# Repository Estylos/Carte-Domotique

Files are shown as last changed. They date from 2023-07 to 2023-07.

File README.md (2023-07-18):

# Carte de contrôle domotique avec ESP32

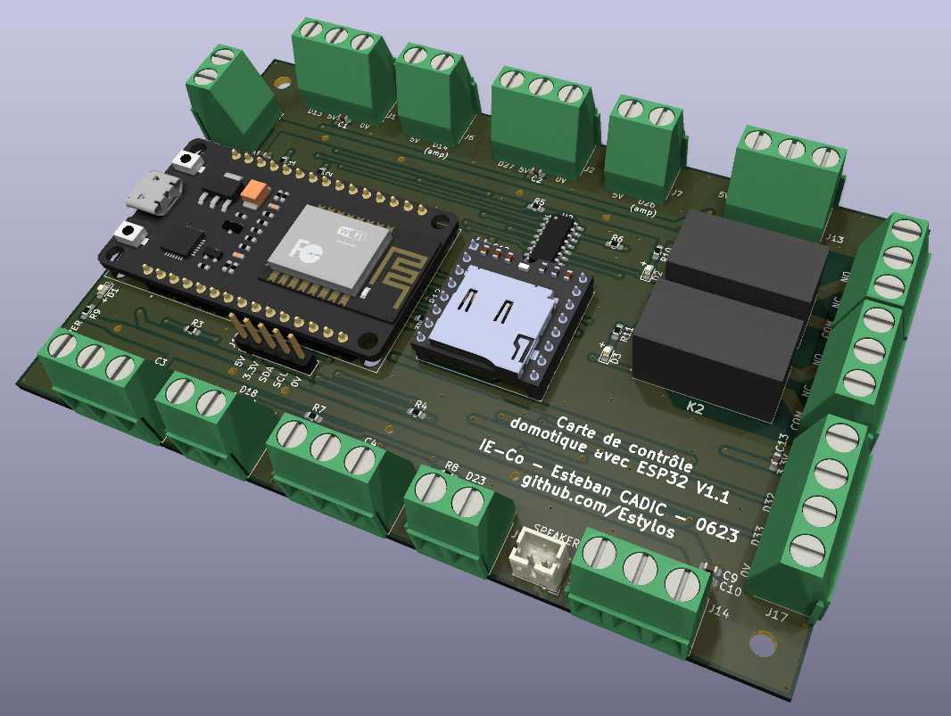
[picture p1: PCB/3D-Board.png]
Visuel 3D


Ce projet prend place dans le cadre de mon stage de fin de 1ère année de cycle ingénieur à l'école Grenoble INP - Esisar, effectué dans le bureau d'études en conception électronique [IE-Concept](https://www.ie-concept.fr/). Un grand merci à l'entreprise de m'avoir permis d'effectuer ce stage dans d'excellentes conditions ainsi que d'autoriser la publication du travail que j'ai pu mener.

## Présentation

L'objectif de ce stage consistait à l'installation d'un système domotique permettant de contrôler les climatiseurs de la société, ainsi que monitorer différents capteurs (température, humidité, présence…) le tout depuis Home Assistant. Ce repo contient seulement la carte électronique basée sur un ESP32 DevKit V1, réalisé sur KiCad ainsi que son boîtier modélisé sur Fusion 360.  

## Objectifs de la carte

La carte domotique conçue permet le branchement de 4 rubans ou anneaux de LEDs adressables WS2812 (pour l'indication lumineuse allant avec le contrôle des clims), 4 LEDs infrarouges, 2 sorties PWM, 1 sortie I2C, 2 relais, 1 port divers avec deux sources de tension (5 et 3.3V) et 2 GPIOs (utilisables par l’ADC1 de l’ESP32). La carte permet aussi le branchement d'un DFPlayer Mini et d'un haut-parleur servant à la lecture de sons depuis une carte SD (et pilotable par Home Assistant).

L'ESP32 peut être configuré directement avec ESPHome, permettant une intégration directe avec Home Assistant. 

## Circuit

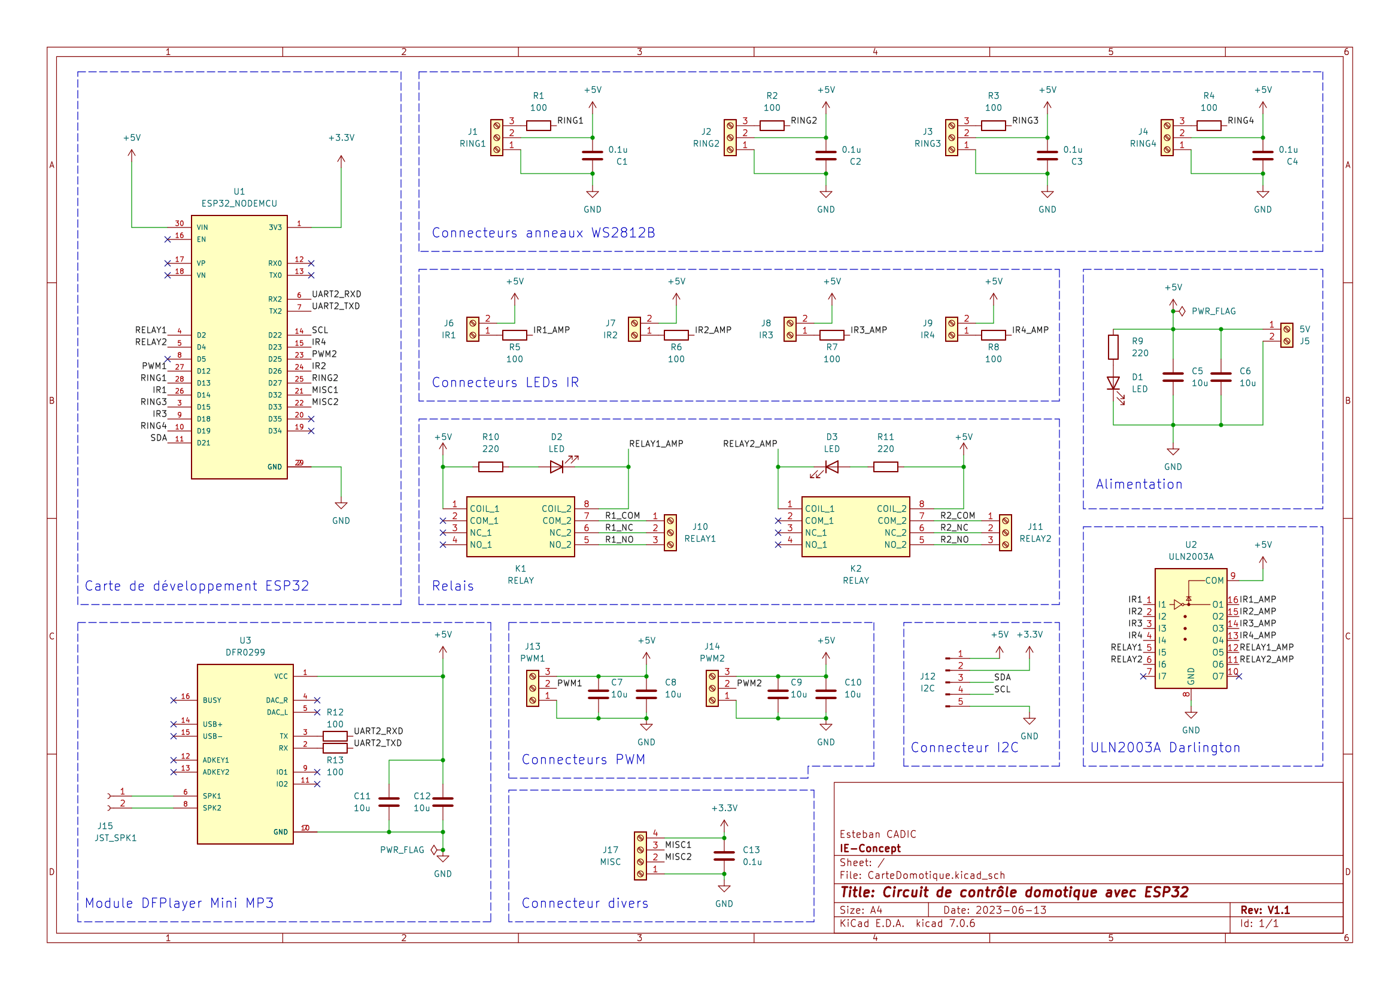
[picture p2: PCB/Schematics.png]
Circuit


Le circuit n'est pas d'une grande complexité. Il s'agit globalement d'un ESP32 avec des borniers à vis, 2 relais, un DFPlayer et quelques composants passifs : condensateurs pour le découplage et résistances pour la limitation de courant. Un réseau de transistors Darlington (ULN2003A) est utilisé afin d'amplifier et de monter à 5V les sorties des LEDs infrarouges contrôlant les climatiseurs et les sorties pour les 2 relais.

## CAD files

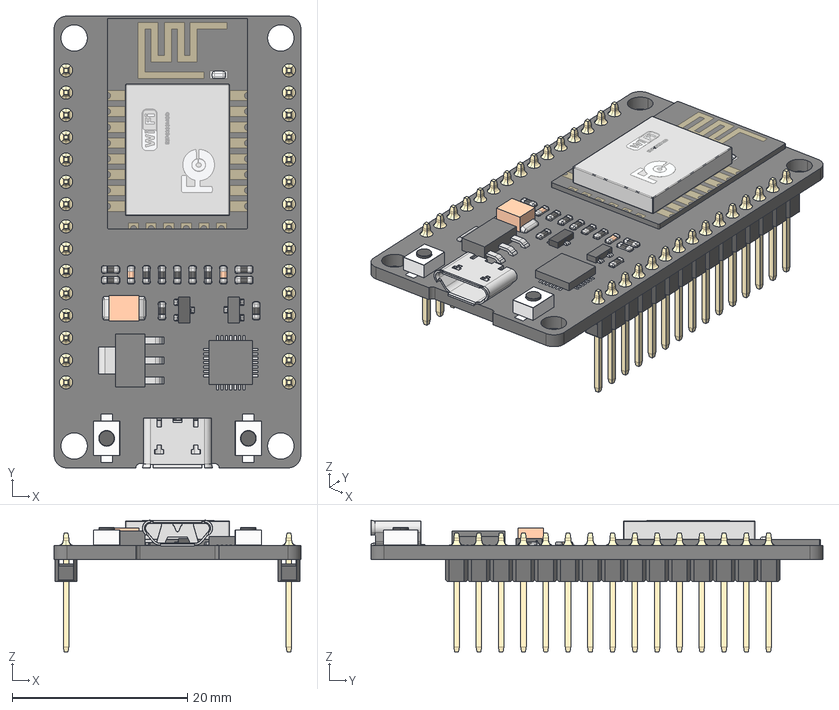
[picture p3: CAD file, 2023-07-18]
PCB/KiCad Files/MISC/ESP32-DEVKIT-V1/esp32_dev_kit_v1_asm.stp
28.1 x 51.5 x 15.0 mm
PCB
PIN x 30
WIFI_CARD_2
RECTANGULARCHIP_2
MICROCHIP_2
TANCHIP_2
TRANSISTOR_3-LEG_2
RESISTOR1_2 x 11
RESISTOR2-32_2 x 2
TRANSISTOR_3-LEG2_2
BUTTONFLASH-13_2 x 2
BUTTONFLASH-14_2 x 2
USB_SOCKET_2

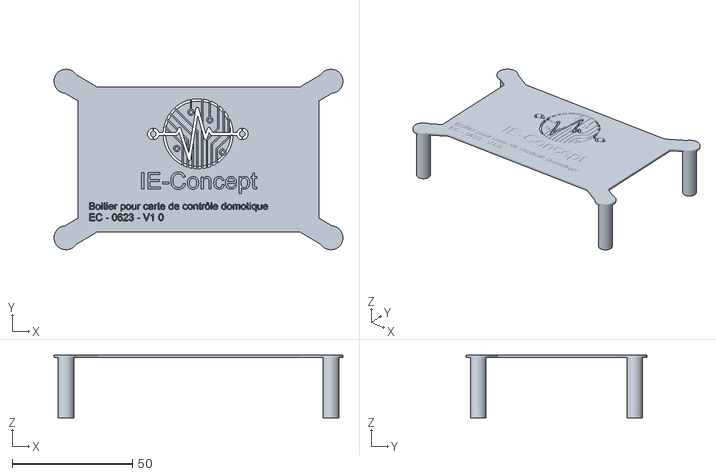
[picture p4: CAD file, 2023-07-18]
CASE/Boite domo TOP v1.stl
120.0 x 75.0 x 26.0

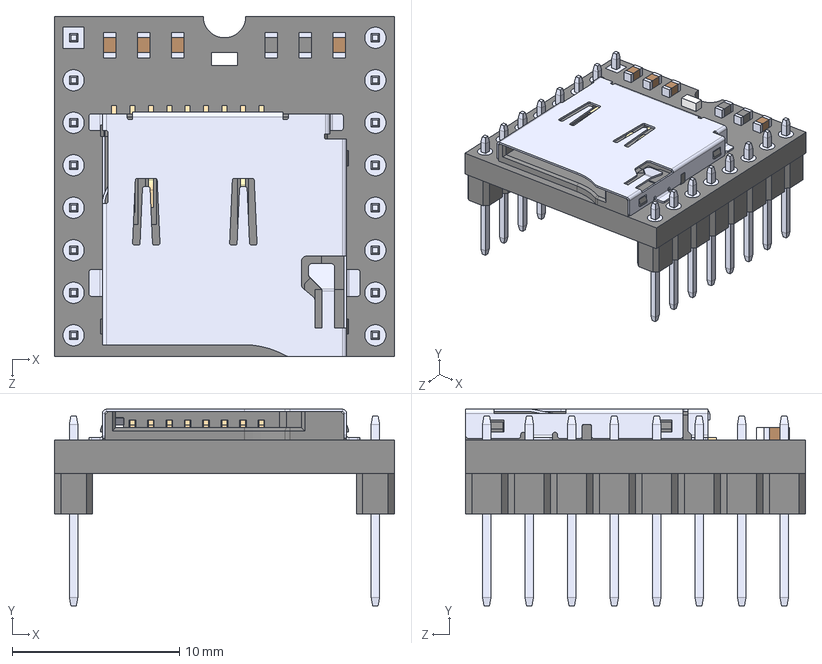
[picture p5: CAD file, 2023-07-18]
PCB/KiCad Files/MISC/DFPLAYER/DFR0299.step
20.3 x 11.8 x 20.3 mm

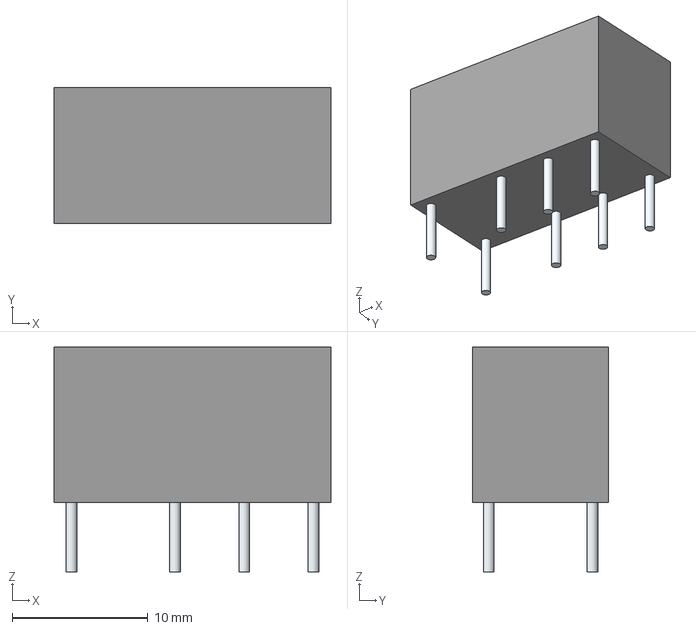
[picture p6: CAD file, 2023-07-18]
PCB/KiCad Files/MISC/RELAY/J104D2C24VDC.20S.stp
20.4 x 9.97 x 16.5 mm
Leads

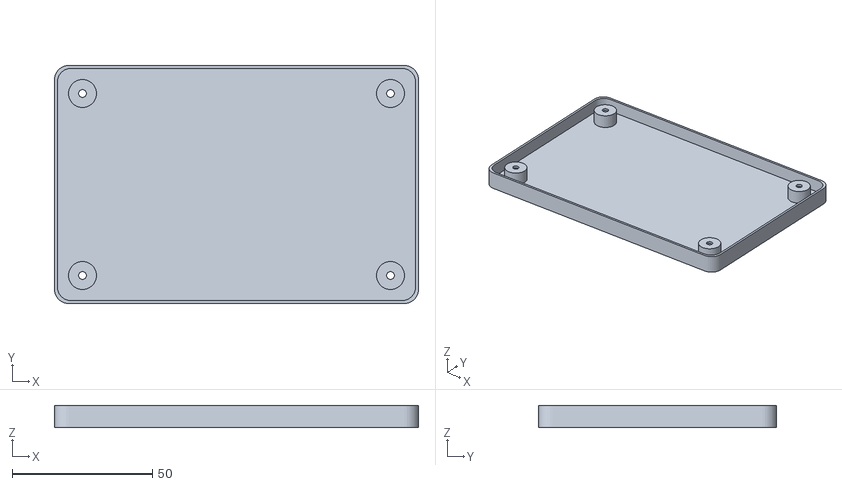
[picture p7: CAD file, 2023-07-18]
CASE/Boite domo BOT v1.stl
130.0 x 85.0 x 8.00

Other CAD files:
CASE/Boite domo v1.f3d

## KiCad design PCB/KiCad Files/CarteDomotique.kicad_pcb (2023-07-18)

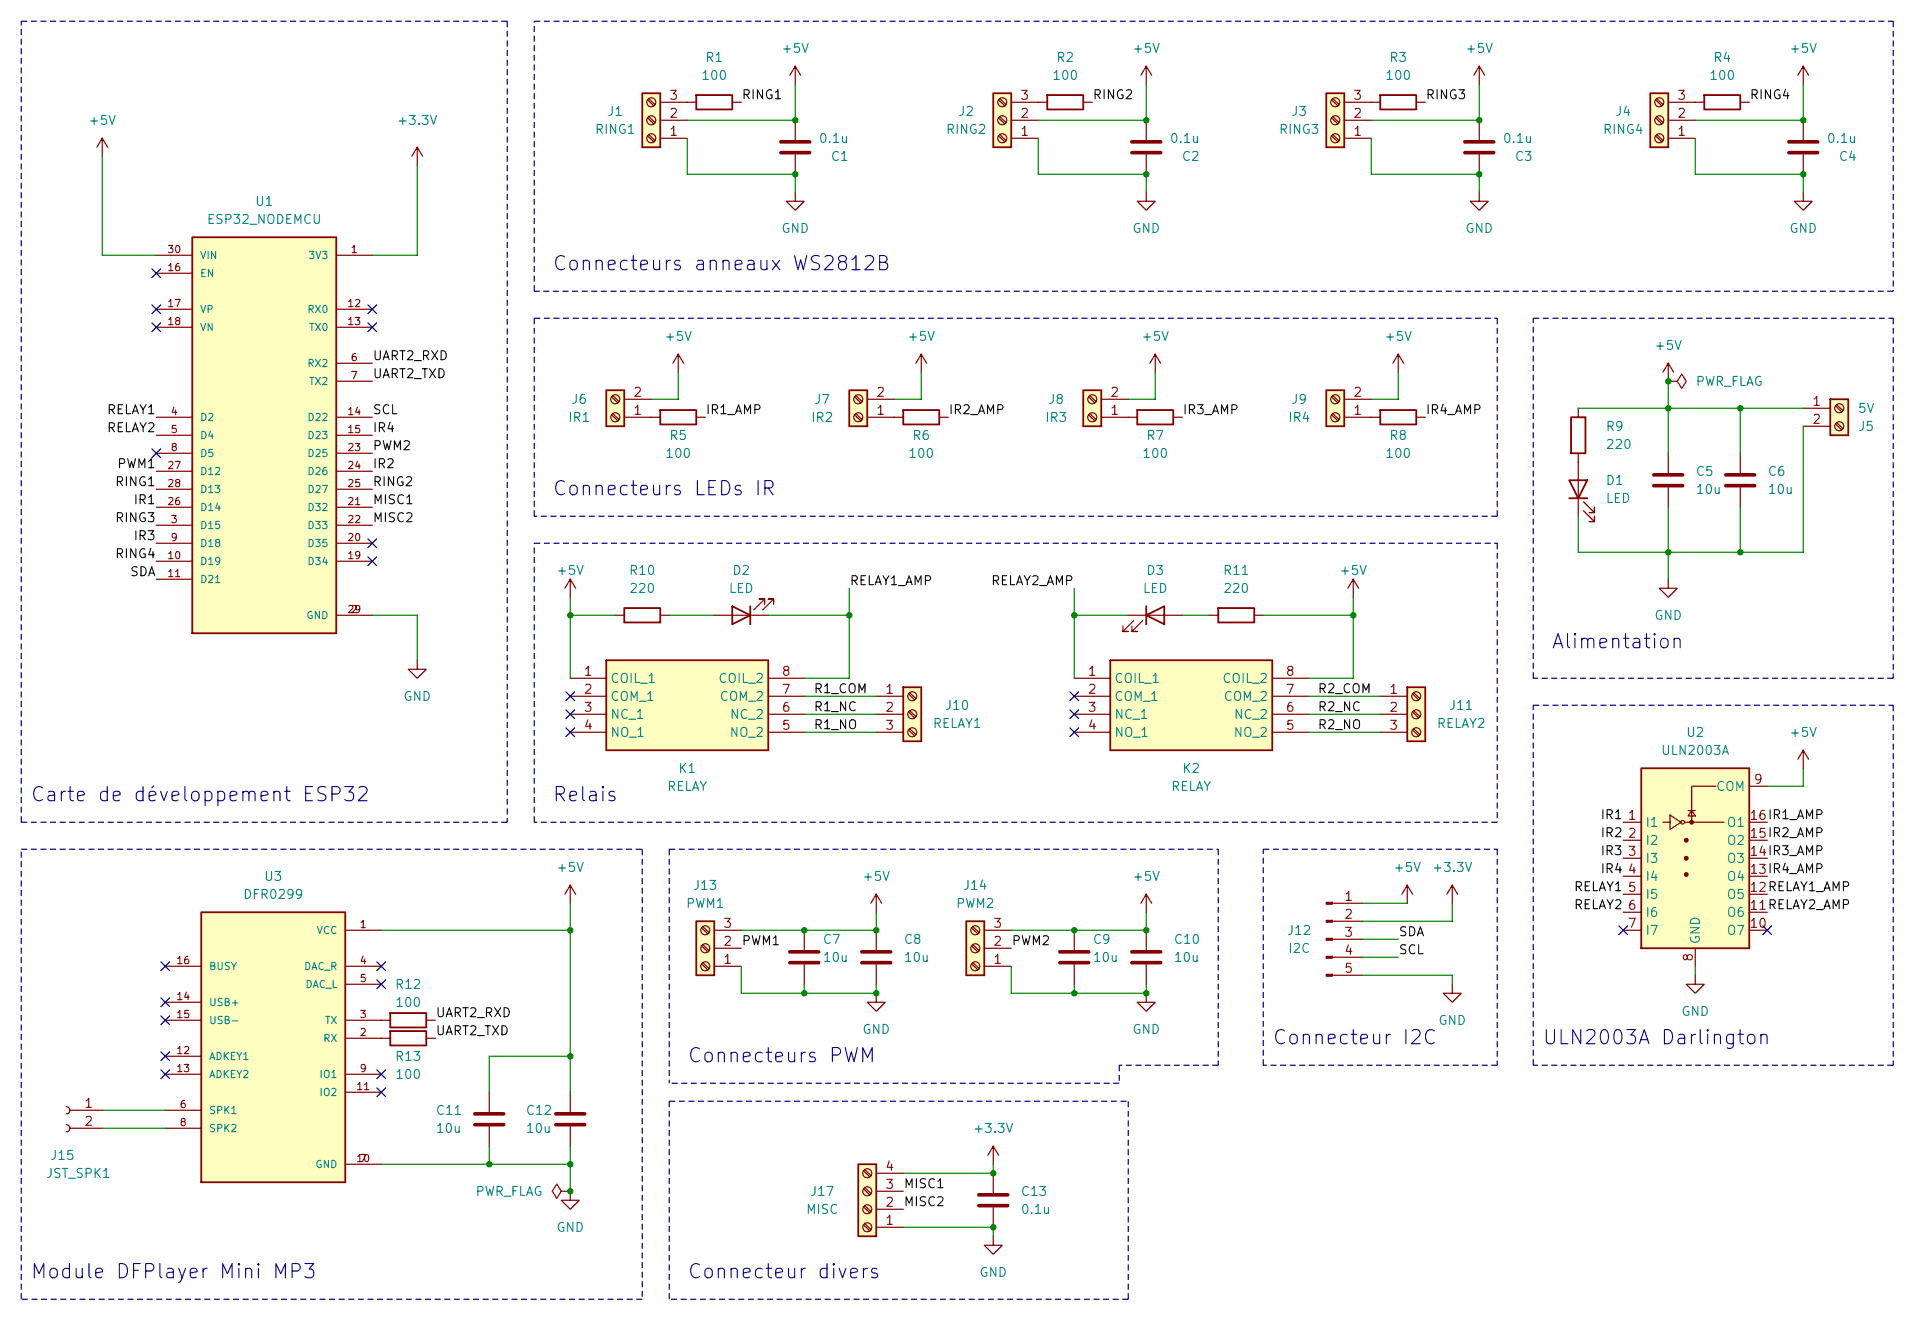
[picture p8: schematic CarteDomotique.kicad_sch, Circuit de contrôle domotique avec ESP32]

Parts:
C1, C2, C3, C4, C13: 0.1u; C_0603_1608Metric_Pad1.08x0.95mm_HandSolder; LCSC Part C14665
C5, C6, C7, C8, C9, C10, C11, C12: 10u; C_0603_1608Metric_Pad1.08x0.95mm_HandSolder; Farnell 9452176
D1, D2, D3: LED; LED_0603_1608Metric_Pad1.05x0.95mm_HandSolder; LCSC Part C84263
J1: RING1; TerminalBlock_bornier-3_P5.08mm; LCSC Part C72334
J2: RING2; TerminalBlock_bornier-3_P5.08mm; LCSC Part C72334
J3: RING3; TerminalBlock_bornier-3_P5.08mm; LCSC Part C72334
J4: RING4; TerminalBlock_bornier-3_P5.08mm; LCSC Part C72334
J5: 5V; TerminalBlock_bornier-2_P5.08mm; LCSC Part C8465
J6: IR1; TerminalBlock_bornier-2_P5.08mm; LCSC Part C8465
J7: IR2; TerminalBlock_bornier-2_P5.08mm; LCSC Part C8465
J8: IR3; TerminalBlock_bornier-2_P5.08mm; LCSC Part C8465
J9: IR4; TerminalBlock_bornier-2_P5.08mm; LCSC Part C8465
J10: RELAY1; TerminalBlock_bornier-3_P5.08mm; LCSC Part C72334
J11: RELAY2; TerminalBlock_bornier-3_P5.08mm; LCSC Part C72334
J12: I2C; PinHeader_1x05_P2.54mm_Vertical; LCSC Part C492404
J13: PWM1; TerminalBlock_bornier-3_P5.08mm; LCSC Part C72334
J14: PWM2; TerminalBlock_bornier-3_P5.08mm; LCSC Part C72334
J15: JST_SPK1; JST_PH_B2B-PH-K_1x02_P2.00mm_Vertical; Farnell 9492534
J17: MISC; TerminalBlock_bornier-4_P5.08mm; LCSC Part C2915641
K1, K2: RELAY; J104D2C24VDC20S; Manufacturer_Part_Number J104D2C24VDC.20S; Digi-Key 2449-J104D2C5VDC.20S-ND
R1, R2, R3, R4, R12, R13: 100; R_0603_1608Metric_Pad0.98x0.95mm_HandSolder; LCSC Part C22775
R5, R6, R7, R8: 100; R_0603_1608Metric_Pad0.98x0.95mm_HandSolder; LCSC Part C107696
R9, R10, R11: 220; R_0603_1608Metric_Pad0.98x0.95mm_HandSolder; LCSC Part C107696
U1: ESP32_NODEMCU; MODULE_ESP32_DEVKIT_V1; PARTREV N/A; JLCPCB BOM 0
U2: ULN2003A; SOIC-16_3.9x9.9mm_P1.27mm; Farnell 2628016
U3: DFR0299; MODULE_DFR0299; JLCPCB BOM 0

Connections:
+3.3V: C13.1, J12.2, J17.4, U1.1 (3V3)
+5V: C1.1, C2.1, C3.1, C4.1, C5.1, C6.1, C7.1, C8.1, C9.1, C10.1, C11.1, C12.1, J1.2, J2.2, J3.2, J4.2, J5.1, J6.2, J7.2, J8.2, J9.2, J12.1, J13.3, J14.3, K1.1 (COIL_1), K2.8 (COIL_2), R9.1, R10.1, R11.1, U1.30 (VIN), U2.9 (COM), U3.1 (VCC)
/IR1: U1.26 (D14), U2.1 (I1)
/IR1_AMP: R5.1, U2.16 (O1)
/IR2: U1.24 (D26), U2.2 (I2)
/IR2_AMP: R6.1, U2.15 (O2)
/IR3: U1.9 (D18), U2.3 (I3)
/IR3_AMP: R7.1, U2.14 (O3)
/IR4: U1.15 (D23), U2.4 (I4)
/IR4_AMP: R8.1, U2.13 (O4)
/MISC1: J17.3, U1.21 (D32)
/MISC2: J17.2, U1.22 (D33)
/PWM1: J13.2, U1.27 (D12)
/PWM2: J14.2, U1.23 (D25)
/R1_COM: J10.1, K1.7 (COM_2)
/R1_NC: J10.2, K1.6 (NC_2)
/R1_NO: J10.3, K1.5 (NO_2)
/R2_COM: J11.1, K2.7 (COM_2)
/R2_NC: J11.2, K2.6 (NC_2)
/R2_NO: J11.3, K2.5 (NO_2)
/RELAY1: U1.4 (D2), U2.5 (I5)
/RELAY1_AMP: D2.1 (K), K1.8 (COIL_2), U2.12 (O5)
/RELAY2: U1.5 (D4), U2.6 (I6)
/RELAY2_AMP: D3.1 (K), K2.1 (COIL_1), U2.11 (O6)
/RING1: R1.1, U1.28 (D13)
/RING2: R2.1, U1.25 (D27)
/RING3: R3.1, U1.3 (D15)
/RING4: R4.1, U1.10 (D19)
/SCL: J12.4, U1.14 (D22)
/SDA: J12.3, U1.11 (D21)
/UART2_RXD: R12.1, U1.6 (RX2)
/UART2_TXD: R13.1, U1.7 (TX2)
GND: C1.2, C2.2, C3.2, C4.2, C5.2, C6.2, C7.2, C8.2, C9.2, C10.2, C11.2, C12.2, C13.2, D1.1 (K), J1.1, J2.1, J3.1, J4.1, J5.2, J12.5, J13.1, J14.1, J17.1, U1.2 (GND), U1.29 (GND), U2.8 (GND), U3.7 (GND), U3.10 (GND)
unnamed: D1.2 (A), R9.2
unnamed: D2.2 (A), R10.2
unnamed: D3.2 (A), R11.2
unnamed: J1.3, R1.2
unnamed: J2.3, R2.2
unnamed: J3.3, R3.2
unnamed: J4.3, R4.2
unnamed: J6.1, R5.2
unnamed: J7.1, R6.2
unnamed: J8.1, R7.2
unnamed: J9.1, R8.2
unnamed: J15.1, U3.6 (SPK1)
unnamed: J15.2, U3.8 (SPK2)
unnamed: R13.2, U3.2 (RX)
unnamed: R12.2, U3.3 (TX)

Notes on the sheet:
Alimentation
Carte de développement ESP32
ULN2003A Darlington
Connecteurs PWM
Module DFPlayer Mini MP3
Connecteurs LEDs IR
Connecteur I2C
Relais
Connecteurs anneaux WS2812B
Connecteur divers

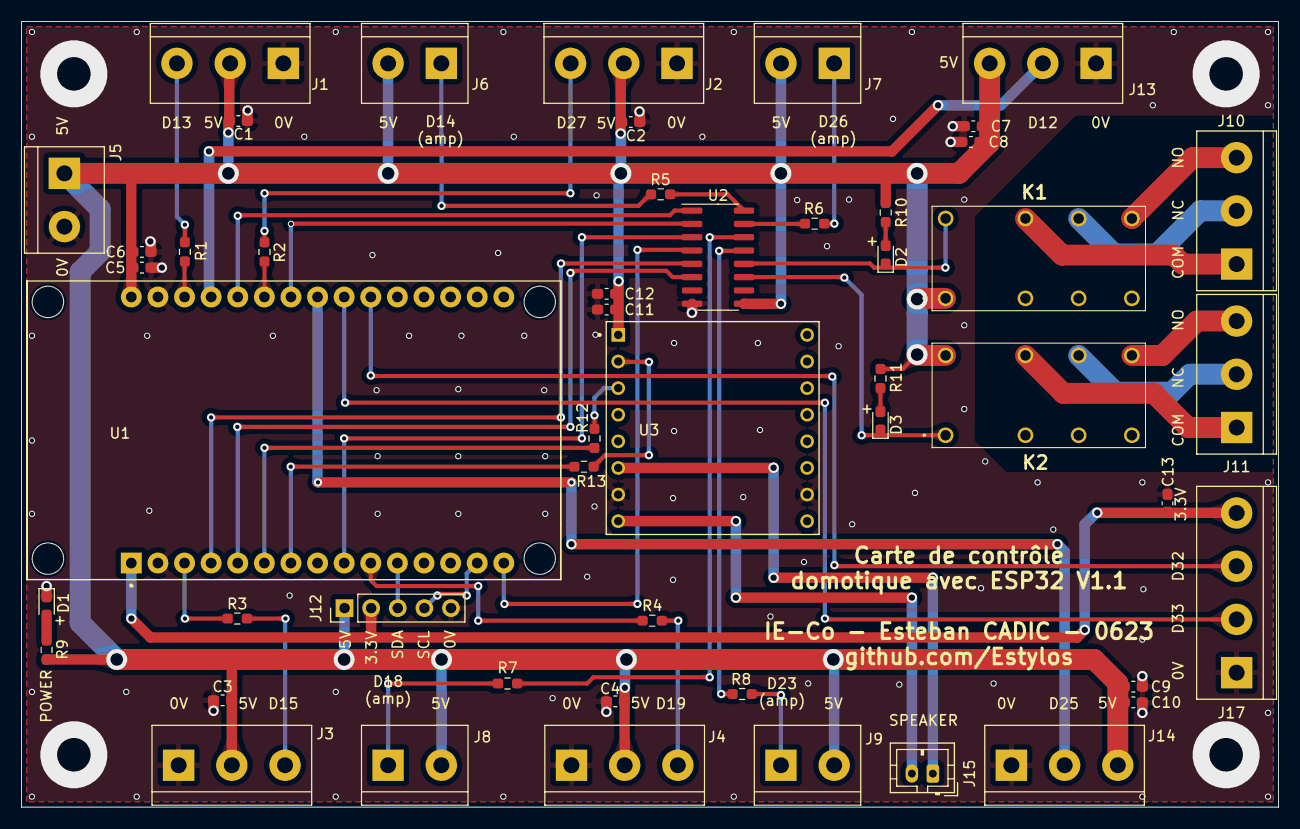
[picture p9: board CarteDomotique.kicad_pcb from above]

Board: 2 copper layers, 120.0 x 75.0 mm, 50 parts (0 on the bottom side), 48 nets.

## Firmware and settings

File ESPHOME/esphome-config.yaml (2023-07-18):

esphome:
  name: esp32-domo1
  friendly_name: ESP32 Domotique 1

# Carte : ESP32 NodeMCU (devkitv1)
esp32:
  board: nodemcu-32s
  framework:
    type: arduino

# Enable logging
logger:

# Enable Home Assistant API
api:
  encryption:
    key: ""

  # For DFPlayer
  services:
  - service: dfplayer_next
    then:
      - dfplayer.play_next:
  - service: dfplayer_previous
    then:
      - dfplayer.play_previous:
  - service: dfplayer_play
    variables:
      file: int
    then:
      - dfplayer.play: !lambda 'return file;'
  - service: dfplayer_play_loop
    variables:
      file: int
      loop_: bool
    then:
      - dfplayer.play:
          file: !lambda 'return file;'
          loop: !lambda 'return loop_;'
  - service: dfplayer_play_folder
    variables:
      folder: int
      file: int
    then:
      - dfplayer.play_folder:
          folder: !lambda 'return folder;'
          file: !lambda 'return file;'

  - service: dfplayer_play_loop_folder
    variables:
      folder: int
    then:
      - dfplayer.play_folder:
          folder: !lambda 'return folder;'
          loop: true

  - service: dfplayer_set_device_tf
    then:
      - dfplayer.set_device: TF_CARD

  - service: dfplayer_set_device_usb
    then:
      - dfplayer.set_device: USB

  - service: dfplayer_set_volume
    variables:
      volume: int
    then:
      - dfplayer.set_volume: !lambda 'return volume;'
  - service: dfplayer_set_eq
    variables:
      preset: int
    then:
      - dfplayer.set_eq: !lambda 'return static_cast<dfplayer::EqPreset>(preset);'

  - service: dfplayer_sleep
    then:
      - dfplayer.sleep

  - service: dfplayer_reset
    then:
      - dfplayer.reset

  - service: dfplayer_start
    then:
      - dfplayer.start

  - service: dfplayer_pause
    then:
      - dfplayer.pause

  - service: dfplayer_stop
    then:
      - dfplayer.stop

  - service: dfplayer_random
    then:
      - dfplayer.random

  - service: dfplayer_volume_up
    then:
      - dfplayer.volume_up

  - service: dfplayer_volume_down
    then:
      - dfplayer.volume_down

ota:
  password: ""

wifi:
  # WiFi entreprise
  ssid: !secret wifi_ssid
  password: !secret wifi_password
  manual_ip:
    static_ip: 192.168.1.100
    gateway: 192.168.1.1
    subnet: 255.255.255.0


  # Fallback
  ap:
    ssid: "ESP32 Domo1 Fallback Hotspot"
    password: ""


# Emetteurs infrarouge

remote_transmitter:
  - id: ir1
    pin:
      number : GPIO14
      inverted : false
    carrier_duty_percent: 50%
  - id: ir2
    pin: 
      number : GPIO26
      inverted : False
    carrier_duty_percent: 50%
  - id: ir3
    pin: 
      number : GPIO18
      inverted : false
    carrier_duty_percent: 50%
  - id: ir4
    pin: 
      number : GPIO23
      inverted : false
    carrier_duty_percent: 50%
    

# Climatiseurs

climate:

  - platform: hitachi_ac344
    name: "Clim 1"
    id: clim1
    transmitter_id : ir1
    visual:
      min_temperature: 16
      max_temperature: 27
      temperature_step: 0.2

  - platform: hitachi_ac344
    name: "Clim 2"
    transmitter_id : ir2
    visual:
      min_temperature: 16
      max_temperature: 27
      temperature_step: 0.2

  - platform: hitachi_ac344
    name: "Clim 3"
    transmitter_id : ir3
    visual:
      min_temperature: 16
      max_temperature: 27
      temperature_step: 0.2


# Anneaux WS2812
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
